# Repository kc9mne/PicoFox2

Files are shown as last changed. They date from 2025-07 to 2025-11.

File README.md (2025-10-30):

Below is the orginal info from AI6YM I have modified the code to enable multiple audio files named audio1.wav though audio8.wav played in order on a cycle.

# PicoFox – A Hackable 2m Fox Transmitter

**PicoFox** is an open source fox transmitter for the 2-meter amateur band, built around the
RP2040 microcontroller (the same chip used in the Raspberry Pi Pico). It’s designed to be simple,
functional, and easy to modify.

PicoFox works well as a standalone fox for portable or walking hunts, but it’s also a great platform
for experimentation. There's ample CPU, flash, and GPIO available if you want to add features like
sensors or interactivity. The transmitter can generate a frequency or phase modulated signal with up
to 2.5kHz (data) bandwidth.

## Key Features
- Transmits FM in the 144–148 MHz band (ITU Zone 1: 144–146 MHz).
- Configured by editing a text file — no software or terminal needed.
- Transmits any 5kHz 16-bit PCM WAV file.
- Automatic Morse code ID with configurable tone, speed, and spacing.
- RF output > 12dBm / 15mW.
- Charges over USB.
- Expansion header provides:
  - 12 GPIOs (including I2C, SPI, UART, ADC).
  - Regulated 3.3V and raw battery voltage.
  - Two additional SI5351 clock outputs

### Getting One

Fully assembled PicoFox units are available from [AI6YM.radio](https://ai6ym.radio/picofox). An
enclosure, battery, and antenna are included. I ship nearly anywhere in the world.

You can also build your own - both the hardware and software are open source for non-commercial use.
For commercial inquiries, contact [justin@ai6ym.radio](mailto:justin@ai6ym.radio).

## Configuration

To configure your PicoFox, connect it to any computer using a micro USB cable. It will appear as a
USB mass storage device (like a flash drive). Open `settings.txt` with a text editor and adjust the
configuration values as needed. Eject the drive, disconnect USB, and power cycle the PicoFox to
apply the new settings.

To reset to factory settings, delete `settings.txt`, eject the drive, disconnect USB, and power
cycle the PicoFox. A default settings file will be regenerated.

### Settings Overview

- `CALLSIGN`: Alphanumeric callsign (max 12 characters).
- `ITU_ZONE`: ITU zone where the transmitter operates (`1`, `2`, or `3`).
- `FREQ_MHZ`: Transmit frequency in MHz.
- `DUTY_CYCLE`: Transmit duty cycle percentage (`0–100`).
- `MORSE_WPM`: Morse ID speed in words per minute.
- `MORSE_FARNSWORTH_WPM`: Slower Farnsworth spacing speed (ignored if lower than `MORSE_WPM`).
- `MORSE_TONE`: Morse tone frequency (100–2000 Hz).
- `MORSE_TONE_VOL`: Morse tone volume percentage (`1–100`).

**Note:** Invalid or missing values may disable the transmitter or revert to safe defaults.

## Using the Transmitter

After configuring settings as described above. The transmitter will turn on following the
provided settings the next time it is turned on.

The transmitter may be powered by an external USB power supply or the internal battery. The internal
battery charges over USB but no indication is available to show battery charging.

**Note: The power switch must be ON to charge the battery over USB. The transmitter will run on USB
power with the switch OFF but the battery will NOT be charged.**

A full battery will last about five hours at 100% duty cycle, 

## Replacing the Audio File

To change the audio transmission, replace the `audio.wav` file in the device’s flash storage. The
audio must be sampled at **5kHz**, **mono** (one channel), and encoded as **signed 16-bit PCM WAV**.

Using **Audacity** (free software available for all major OSs):

1. Set "Project Rate (Hz)" to `5000`.
2. Import, record, or generate your audio.
3. Mix down to a single mono track.
4. Export as WAV using **Signed 16-bit PCM** encoding.
5. Name the file `audio.wav` and copy it to the device.
6. Eject the drive and disconnect USB.
7. Power cycle the PicoFox.

**Notes:**

- Improper format may prevent audio transmission or cause noise to be transmitted instead.
- The audio is transmitted, followed by the morse ID, and then the transmitter turns off if
  `DUTY_CYCLE < 100`. In this way the length of the audio determines the transmit cycle time and the
  frequency of morse code ID transmissions. **YOU ARE RESPONSIBLE FOR COMPLYING WITH LOCAL LAWS FOR
  TRANSMITTING YOUR CALLSIGN!**
- To restore the default audio, delete `audio.wav`, eject the drive, disconnect USB, and power cycle
  the PicoFox.

## Design Brief

An SI5351 clock generator, locked to a TCXO, provides the RF signal. Modulation is applied in
software by the RP2040. To achieve smooth FM output, modulation is handled on core 1 with
I<sup>2</sup>C running at 1 MHz. Register writes are minimized and no other devices are on
I<sup>2</sup>C0.

Core 0 manages flash operations. Most extensions or new features should run on core 0.

**Note:** Mounting the device as a USB mass storage device will interrupt clean modulation as both
cores are blocked during flash operations.

The SPI flash device is split into program memory and a FAT16 filesystem. The filesystem contains
a text file for user-supplied settings, an audio file for transmission, a second audio file
containing the generated morse code ID, and a hash file used to detect changes to the settings file.
Unexpected files are automatically deleted and missing files are re-created from defaults in the
firmware binary.

The design intentionally includes large amounts of free CPU cycles, RAM, and flash so that cool
things can be built on the PicoFox.

## Development Guide

### Build Environment Setup

- Install Arduino IDE >= 2.3.
- Install libraries - Adafruit SPIFlash, Adafruit TinyUSB, Etherkit Si5351.
- Install board package from [my fork of Arduino-Pico](https://github.com/ai6ym/arduino-pico). This
  will be merged upstream eventually but for now you'll need the changes in my fork.
- In `Tools -> Board` select the `Raspberry Pi RP2040/RP2350 Boards -> AI6YM PicoFox`.
- Connect your PicoFox and select the appropriate TTY / COM port.

On Linux it may be necessary to add udev rules for this device. The relevant rules from my system
are below. I have no idea how this works on other operating systems. Mac is probably similar,
Windows should not be used for software developement of any kind (or really anything).

```
# Make an RP2040 in BOOTSEL mode writable by all users, so you can `picotool`
# without `sudo`. 
SUBSYSTEM=="usb", ATTRS{idVendor}=="2e8a", ATTRS{idProduct}=="0003", MODE="0666"

# Symlink an RP2040 running MicroPython from /dev/pico.
#
# Then you can `mpr connect $(realpath /dev/pico)`.
SUBSYSTEM=="tty", ATTRS{idVendor}=="2e8a", ATTRS{idProduct}=="0005", SYMLINK+="pico"

# Adafruit TinyUSB stack.
SUBSYSTEM=="tty", ATTRS{idVendor}=="239a", ATTRS{idProduct}=="cafe", MODE="0666"
SUBSYSTEM=="usb", ATTRS{idVendor}=="239a", ATTRS{idProduct}=="cafe", MODE="0666"
```

### Compilation Settings

- `Flash Size`: `16MB (Sketch: 1MB, FS: 15MB)`
- `CPU Speed`: `TBD`
- `USB Stack`: `Adafruit TinyUSB`

If needed for some reason you could change the partition layout to give more space for the sketch.
Doing so would destroy all data but the code automatically formats the partition and writes
defaults.

All other settings are fine at default values.

### Recovering a Board

In general the UF2 upload process will work fine. Click the upload button, after compilation the IDE
will push the board into UF2 update mode, write the new binary, and then reset the board to normal
operation.

If that doesn't work try the following:
- Reset the board and try again. Just tap the `RESET` button on the board to reset the RP2040.
- Force the device into `BOOTSEL` mode. Hold the `BOOTSEL` button, tap the `RESET` button, and then
  release the `BOOTSEL` button.
- Force the device into `BOOTSEL` mode **AND** change `Tools -> Upload Method` to `PicoTool`.
- When all else fails grab a PicoProbe (or a Pico / Pico2 flashed with the PicoProbe binary),
  connect that to the debug header of the PicoFox, and change `Tools -> Upload Method` to
  `Picoprobe`.
- If all of the above fails, well, he's dead Jim.

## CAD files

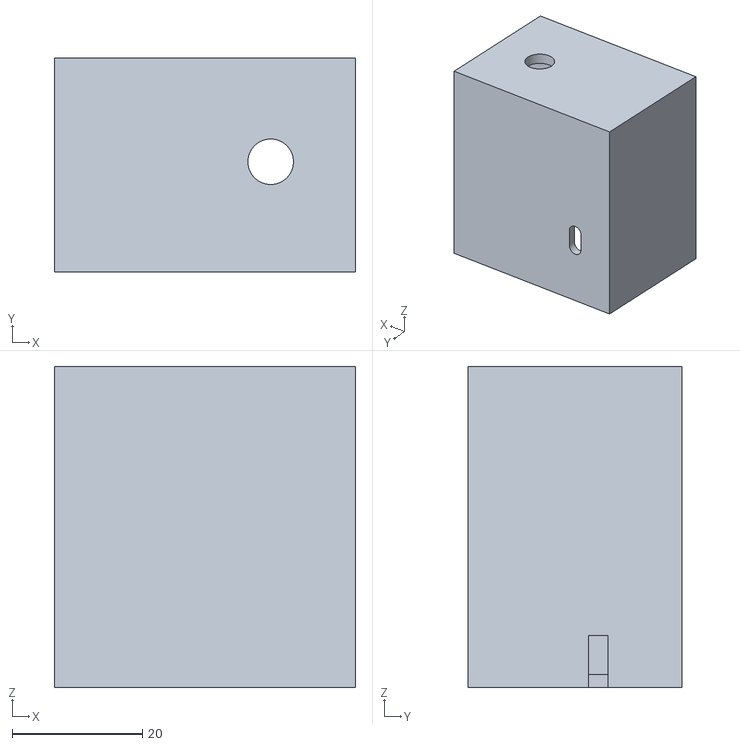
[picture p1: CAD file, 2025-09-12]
enclosure/Enclosure Body.stl
46.3 x 32.9 x 49.3

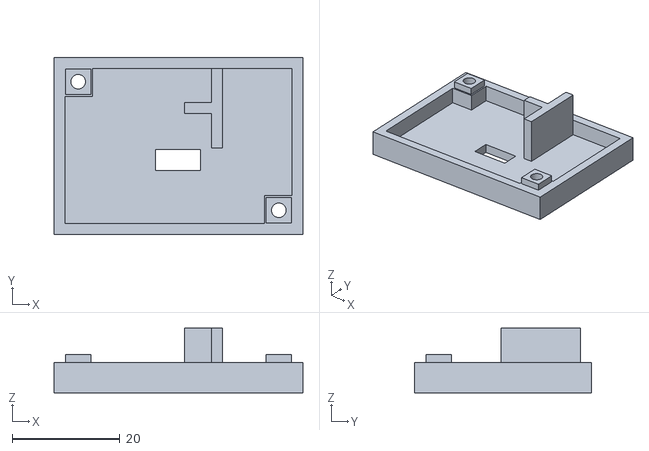
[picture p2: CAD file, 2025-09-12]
enclosure/Enclosure Top.stl
46.3 x 32.9 x 12.0

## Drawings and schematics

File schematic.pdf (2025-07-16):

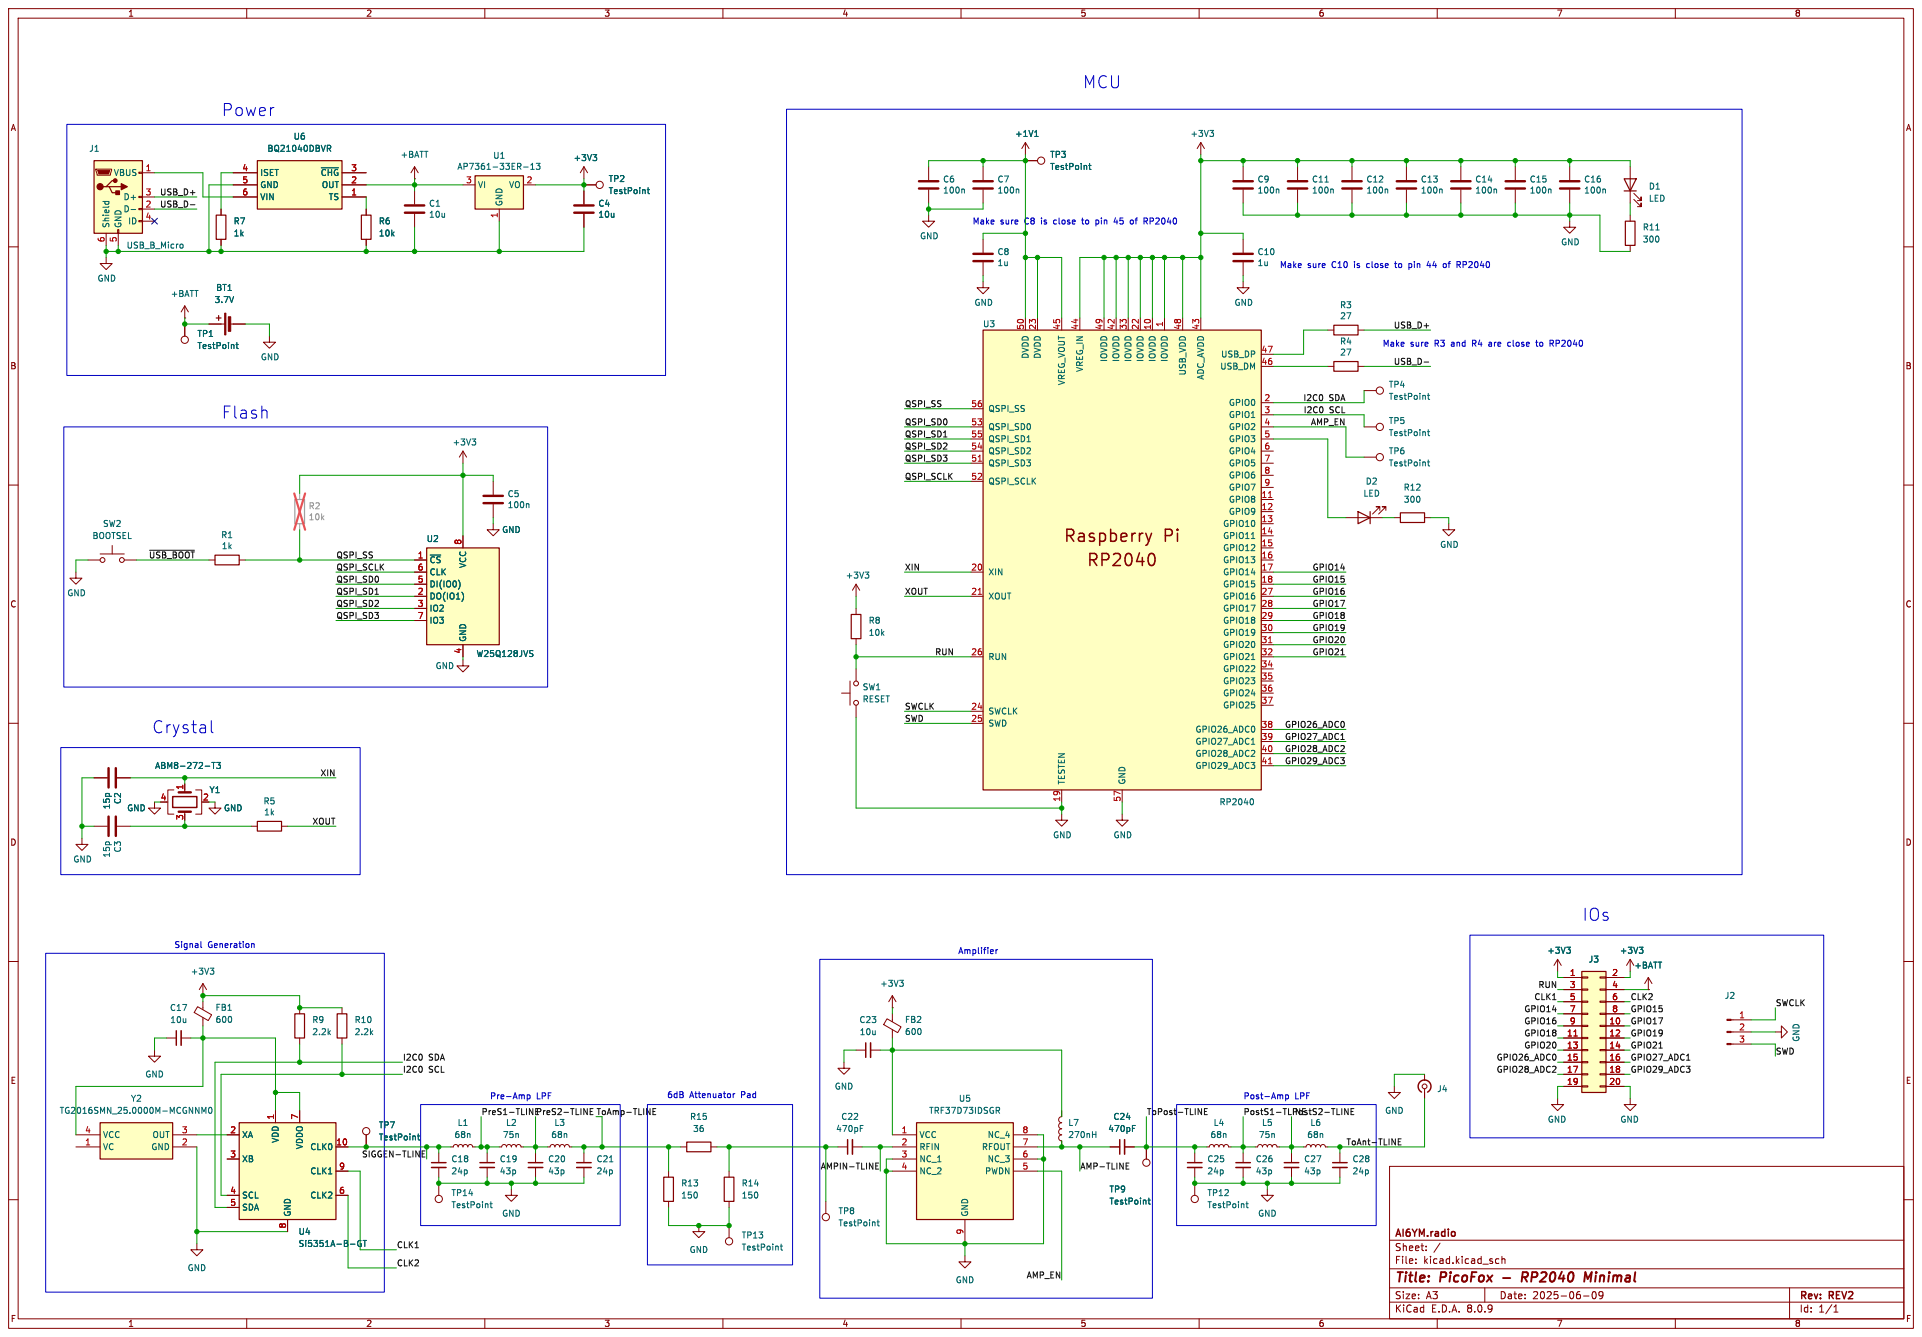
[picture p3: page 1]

1 IOVDD 10 GPIO8 11 GPIO9 12 GPIO10 13 GPIO11 14 GPIO12 15 GPIO13 16 GPIO14 17 GPIO15 18 TESTEN 19 GPIO0 2 XIN 20 XOUT 21 IOVDD 22 DVDD 23 SWCLK 24 SWD 25 RUN 26 GPIO16 27 GPIO17 28 GPIO18 29 GPIO1 3 GPIO19 30 GPIO20 31 GPIO21 32 IOVDD 33 GPIO22 34 GPIO23 35 GPIO24 36 GPIO25 37 GPIO26_ADC0 38 GPIO27_ADC1 39 GPIO2 4 GPIO28_ADC2 40 GPIO29_ADC3 41 IOVDD 42 ADC_AVDD 43 VREG_IN 44 VREG_VOUT 45 USB_DM 46 USB_DP 47 USB_VDD 48 IOVDD 49 GPIO3 5 DVDD 50 QSPI_SD3 51 QSPI_SCLK 52 QSPI_SD0 53 QSPI_SD2 54 QSPI_SD1 55 QSPI_SS 56 GND 57 GPIO4 6 GPIO5 7 GPIO6 8 GPIO7 9 U3 RP2040 GND

1 CLK0 10 XA 2 XB 3 SCL 4 SDA 5 CLK2 6 VDDO

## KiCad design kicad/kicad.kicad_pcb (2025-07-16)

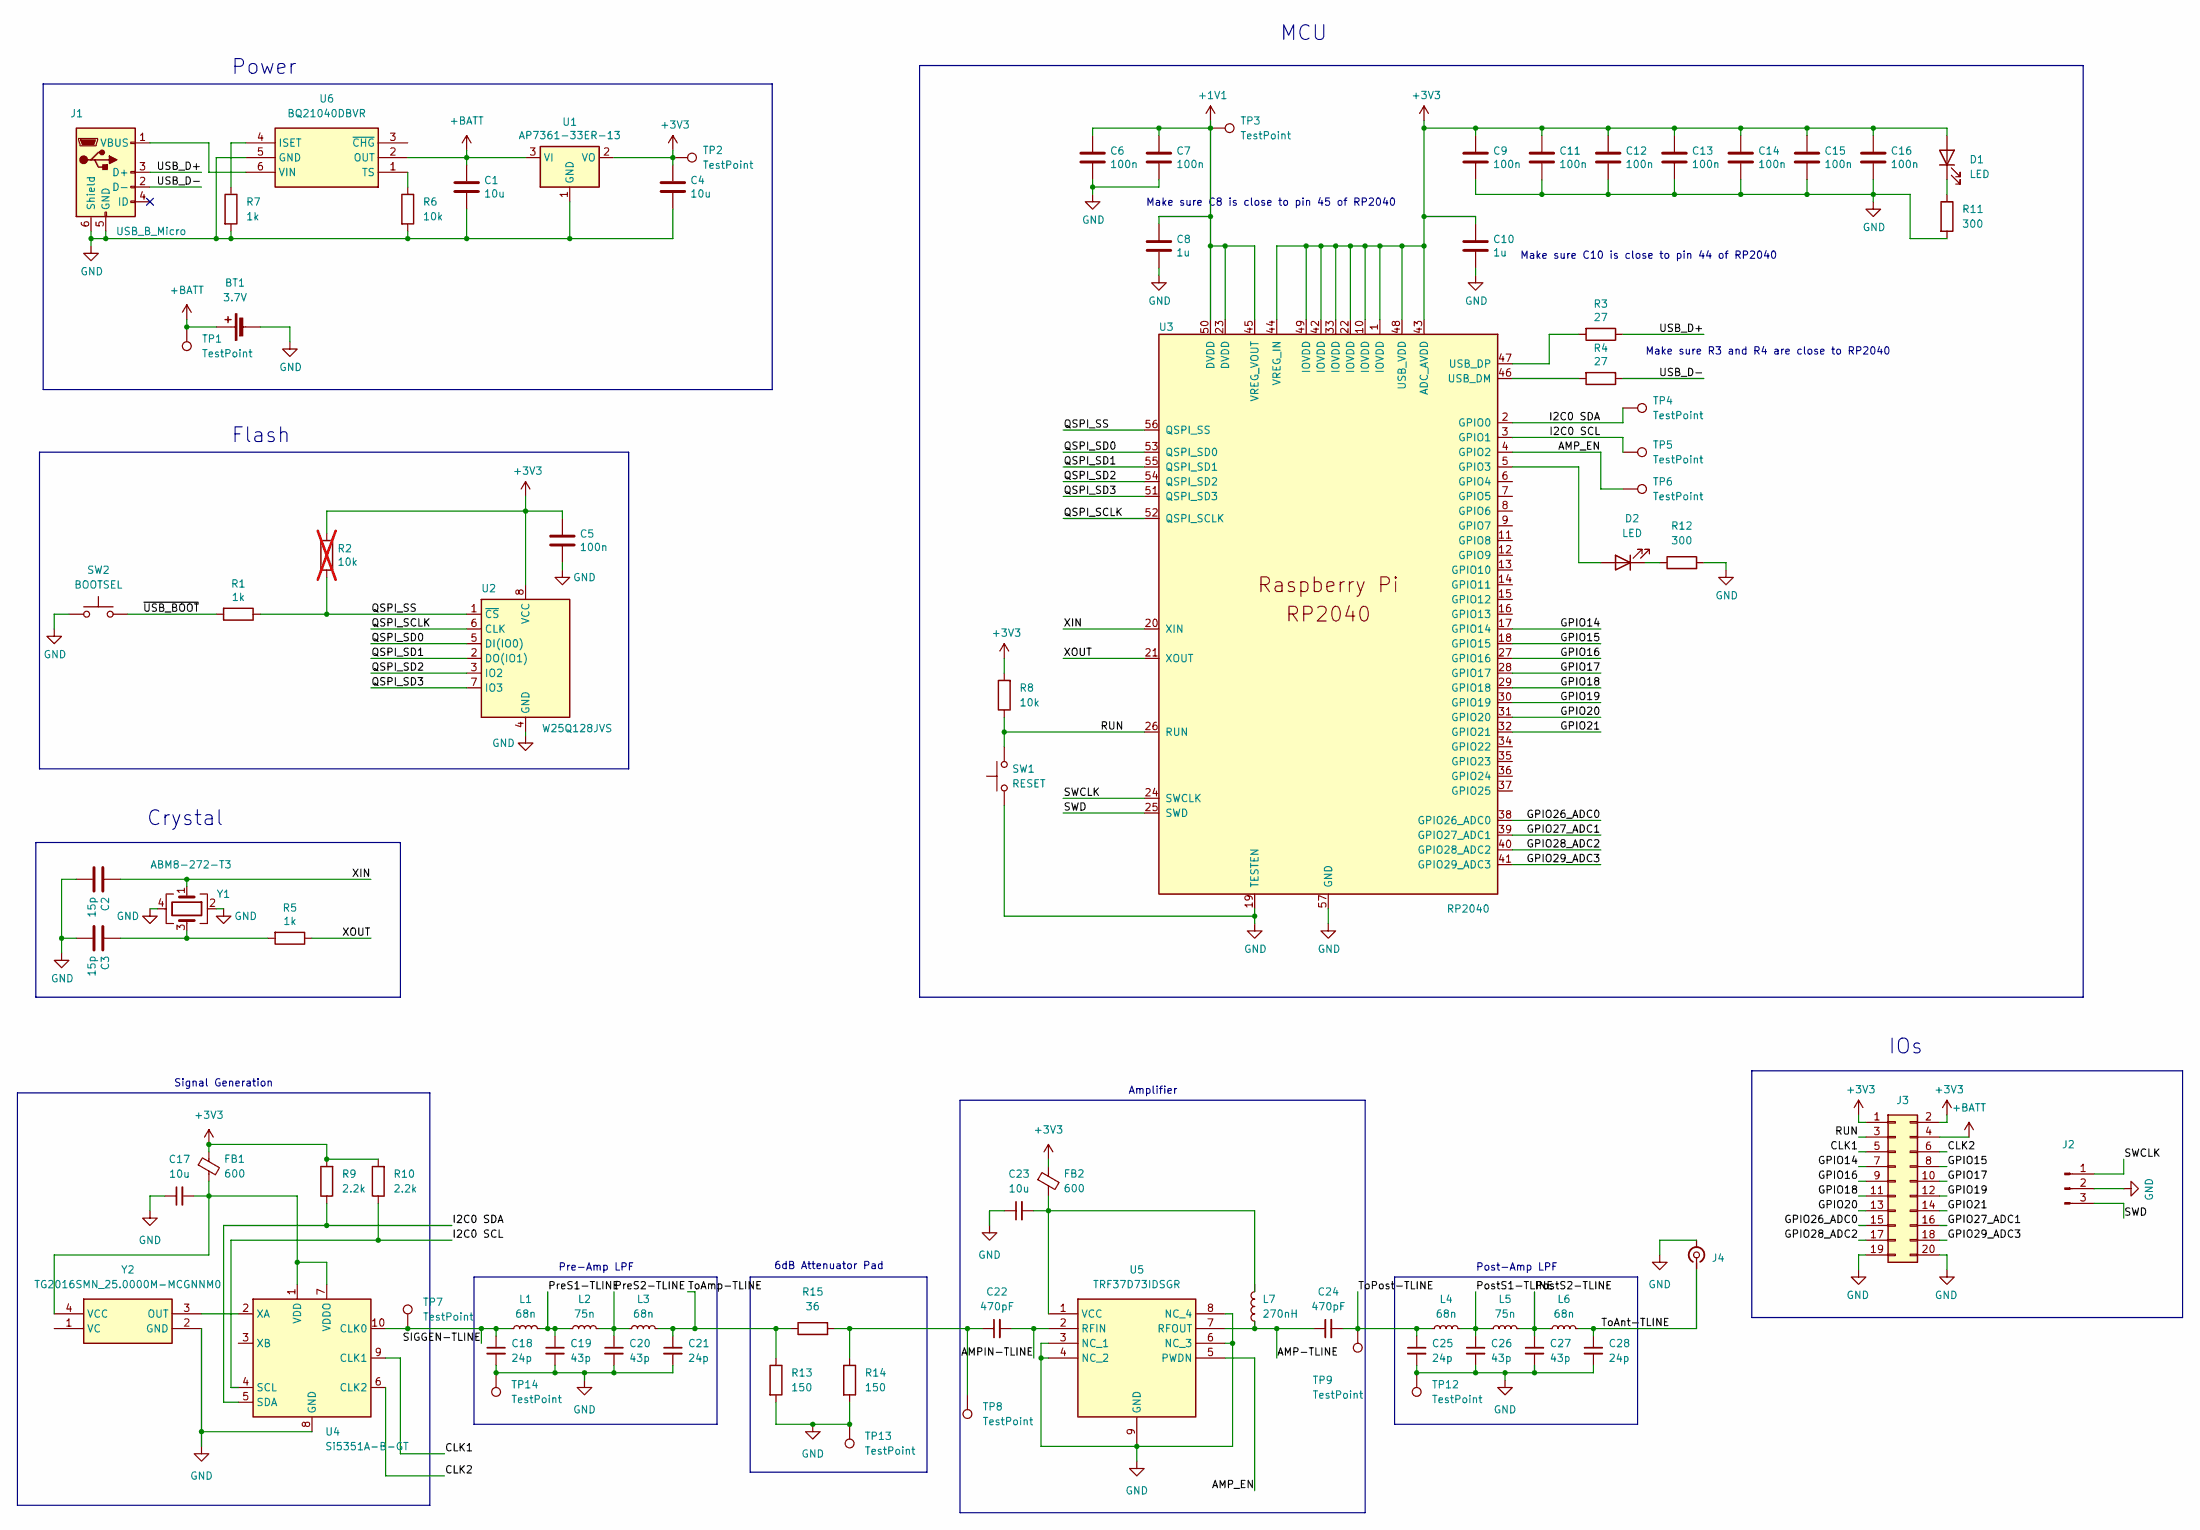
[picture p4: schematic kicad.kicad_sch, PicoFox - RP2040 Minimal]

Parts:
BT1: 3.7V; JST_PH_B2B-PH-K_1x02_P2.00mm_Vertical
C1, C4, C17, C23: 10u; C_0402_1005Metric
C2, C3: 15p; C_0402_1005Metric
C5, C6, C7, C9, C11, C12, C13, C14, C15, C16: 100n; C_0402_1005Metric
C8, C10: 1u; C_0402_1005Metric
C18, C21, C25, C28: 24p; C_0402_1005Metric
C19, C20, C26, C27: 43p; C_0402_1005Metric
C22, C24: 470pF; C_0402_1005Metric
D1, D2: LED; LED_0805_2012Metric
FB1, FB2: 600; L_0402_1005Metric
J1: USB_B_Micro; USB_Micro-B_Amphenol_10103594-0001LF_Horizontal_modified
J2: Conn_01x03_Pin; PinHeader_1x03_P2.54mm_Vertical
J3: Conn_02x10_Counter_Clockwise; PinHeader_2x10_P2.54mm_Vertical
J4: Conn_Coaxial_Small; SMA_Amphenol_901-143_Horizontal
L1, L3, L4, L6: 68n; L_0402_1005Metric
L2, L5: 75n; L_0402_1005Metric
L7: 270nH; L_0402_1005Metric
R1, R5, R7: 1k; R_0402_1005Metric
R2: 10k; R_0402_1005Metric; not fitted
R3, R4: 27; R_0402_1005Metric
R6, R8: 10k; R_0402_1005Metric
R9, R10: 2.2k; R_0402_1005Metric
R11, R12: 300; R_0402_1005Metric
R13, R14: 150; R_0402_1005Metric
R15: 36; R_0402_1005Metric
SW1: RESET; SW_Push_SPST_NO_Alps_SKRK
SW2: BOOTSEL; SW_Push_SPST_NO_Alps_SKRK
TP1, TP2, TP3, TP4, TP5, TP6, TP7, TP8, TP9, TP12, TP13, TP14: TestPoint; TestPoint_Pad_D1.0mm
U1: AP7361-33ER-13; SOT-223-3_TabPin2
U2: W25Q128JVS; SOIC-8_5.23x5.23mm_P1.27mm
U3: RP2040; RP2040-QFN-56
U4: Si5351A-B-GT; MSOP-10_3x3mm_P0.5mm
U5: TRF37D73IDSGR; WSON-8-1EP_2x2mm_P0.5mm_EP0.9x1.6mm; Mouser Part Number 595-TRF37D73IDSGR
U6: BQ21040DBVR; SOT95P280X145-6N; Mouser Part Number 595-BQ21040DBVR
Y1: ABM8-272-T3; Crystal_SMD_3225-4Pin_3.2x2.5mm
Y2: TG2016SMN_25.0000M-MCGNNM0; TG2016SMN250000MMCGNNM0; Mouser Part Number 732-2016SMN25MCGNNM0

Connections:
+1V1: C6.1, C7.1, C8.1, TP3.1, U3.23 (DVDD), U3.45 (VREG_VOUT), U3.50 (DVDD)
+3V3: C4.1, C5.1, C9.1, C10.1, C11.1, C12.1, C13.1, C14.1, C15.1, C16.1, D1.2 (A), FB1.1, FB2.1, J3.1, J3.2, R2.1, R8.2, R9.2, R10.2, TP2.1, U1.2 (VO), U2.8 (VCC), U3.1 (IOVDD), U3.10 (IOVDD), U3.22 (IOVDD), U3.33 (IOVDD), U3.42 (IOVDD), U3.43 (ADC_AVDD), U3.44 (VREG_IN), U3.48 (USB_VDD), U3.49 (IOVDD)
+BATT: BT1.1 (+), C1.1, J3.4, TP1.1, U1.3 (VI), U6.2 (OUT)
/AMP-TLINE: C24.1, L7.1, U5.7 (RFOUT); also elsewhere on the board
/AMPIN-TLINE: C22.2, U5.2 (RFIN)
/AMP_EN: TP6.1, U3.4 (GPIO2), U5.5 (PWDN)
/CLK1: J3.5, U4.9 (CLK1)
/CLK2: J3.6, U4.6 (CLK2)
/GPIO14: J3.7, U3.17 (GPIO14)
/GPIO15: J3.8, U3.18 (GPIO15)
/GPIO16: J3.9, U3.27 (GPIO16)
/GPIO17: J3.10, U3.28 (GPIO17)
/GPIO18: J3.11, U3.29 (GPIO18)
/GPIO19: J3.12, U3.30 (GPIO19)
/GPIO20: J3.13, U3.31 (GPIO20)
/GPIO21: J3.14, U3.32 (GPIO21)
/GPIO26_ADC0: J3.15, U3.38 (GPIO26_ADC0)
/GPIO27_ADC1: J3.16, U3.39 (GPIO27_ADC1)
/GPIO28_ADC2: J3.17, U3.40 (GPIO28_ADC2)
/GPIO29_ADC3: J3.18, U3.41 (GPIO29_ADC3)
/I2C0 SCL: R10.1, TP5.1, U3.3 (GPIO1), U4.4 (SCL)
/I2C0 SDA: R9.1, TP4.1, U3.2 (GPIO0), U4.5 (SDA)
/PostS1-TLINE: C26.1, L4.2, L5.1
/PostS2-TLINE: C27.1, L5.2, L6.1
/PreS1-TLINE: C19.1, L1.2, L2.1
/PreS2-TLINE: C20.1, L2.2, L3.1
/QSPI_SCLK: U2.6 (CLK), U3.52 (QSPI_SCLK)
/QSPI_SD0: U2.5 (DI(IO0)), U3.53 (QSPI_SD0)
/QSPI_SD1: U2.2 (DO(IO1)), U3.55 (QSPI_SD1)
/QSPI_SD2: U2.3 (IO2), U3.54 (QSPI_SD2)
/QSPI_SD3: U2.7 (IO3), U3.51 (QSPI_SD3)
/QSPI_SS: R1.1, R2.2, U2.1 (~CS), U3.56 (QSPI_SS)
/RUN: J3.3, R8.1, SW1.2, U3.26 (RUN)
/SIGGEN-TLINE: C18.1, L1.1, TP7.1, U4.10 (CLK0)
/SWCLK: J2.1, U3.24 (SWCLK)
/SWD: J2.3, U3.25 (SWD)
/ToAmp-TLINE: C21.1, L3.2, R13.1, R15.1
/ToAnt-TLINE: C28.1, J4.1 (In), L6.2
/ToPost-TLINE: C24.2, C25.1, L4.1, TP9.1
/USB_D+: J1.3 (D+), R3.1
/USB_D-: J1.2 (D-), R4.1
/XIN: C2.1, U3.20 (XIN), Y1.1
/XOUT: R5.1, U3.21 (XOUT)
/~USB_BOOT: R1.2, SW2.2
GND: BT1.2 (-), C1.2, C2.2, C3.2, C4.2, C5.2, C6.2, C7.2, C8.2, C9.2, C10.2, C11.2, C12.2, C13.2, C14.2, C15.2, C16.2, C17.1, C18.2, C19.2, C20.2, C21.2, C23.1, C25.2, C26.2, C27.2, C28.2, J1.5 (GND), J1.6 (Shield), J2.2, J3.19, J3.20, J4.2 (Ext), R6.2, R7.2, R11.2, R12.2, R13.2, R14.2, SW1.1, SW2.1, TP12.1, TP13.1, TP14.1, U1.1 (GND), U2.4 (GND), U3.19 (TESTEN), U3.57 (GND), U4.8 (GND), U5.3 (NC_1), U5.4 (NC_2), U5.6 (NC_3), U5.8 (NC_4), U5.9 (GND), U6.5 (GND), Y1.2, Y1.4, Y2.2 (GND)
unnamed: C3.1, R5.2, Y1.3
unnamed: C22.1, R14.1, R15.2, TP8.1
unnamed: D1.1 (K), R11.1
unnamed: D2.2 (A), U3.5 (GPIO3)
unnamed: D2.1 (K), R12.1
unnamed: J1.1 (VBUS), U6.6 (VIN)
unnamed: R4.2, U3.46 (USB_DM)
unnamed: R3.2, U3.47 (USB_DP)
unnamed: C17.2, FB1.2, U4.1 (VDD), U4.7 (VDDO), Y2.4 (VCC)
unnamed: U4.2 (XA), Y2.3 (OUT)
unnamed 55: C23.2, FB2.2, U5.1 (VCC); also elsewhere on the board
unnamed: R7.1, U6.4 (ISET)
unnamed: R6.1, U6.1 (TS)

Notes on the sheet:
IOs
Power
Amplifier
Make sure C8 is close to pin 45 of RP2040
Crystal
Pre-Amp LPF
Make sure C10 is close to pin 44 of RP2040
Post-Amp LPF
Signal Generation
Make sure R3 and R4 are close to RP2040
Flash
6dB Attenuator Pad
MCU

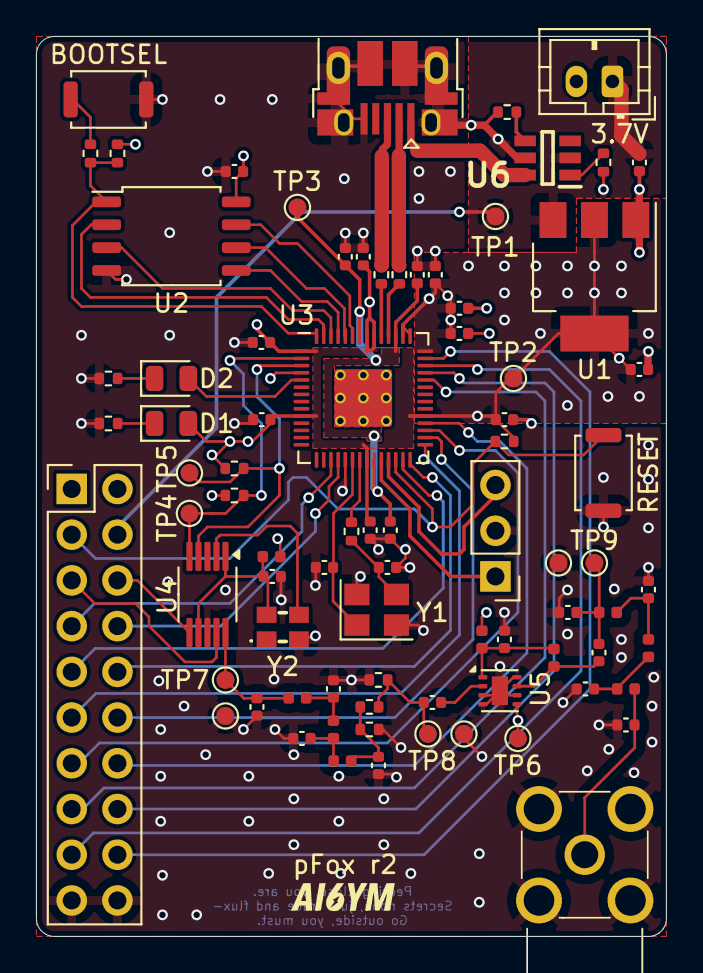
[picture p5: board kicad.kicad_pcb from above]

Board: 4 copper layers, 35.0 x 50.0 mm, 81 parts (0 on the bottom side), 58 nets.

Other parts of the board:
FB3: 600; L_0402_1005Metric

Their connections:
/AMP-TLINE: FB3.1; also elsewhere on the board
unnamed 55: FB3.2; also elsewhere on the board

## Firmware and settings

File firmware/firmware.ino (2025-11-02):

/* PicoFox - 2M FM Fox Transmitter

Modified BY KC9MNE to play multiple wav files in sequence, and have better audio quality.
below is AI6YM's original header, All base and foundational work is credited to him!
---------------------------------------------------------------------------------------
Copyright 2025 Giorgi Enterprises LLC dba AI6YM.radio.
License: Creative Commons Attribution-NonCommercial-ShareAlike 4.0 International (see LICENSE file).

COMMERCIAL USE OF THIS CODE AND ANY DERIVATIVE IS FORBIDDEN WITHOUT PERMISSION FROM THE COPYRIGHT HOLDER!

You may configure this software without compiling and flashing. Simply connect the device to your PC with a USB cable and edit the
settings.txt file. You may also change the audio which is played between morse code IDs by replacing the audio.wav file. The file you
provide MUST be 5kHz sampling, unsigned 16bit PCM audio.

The device may be reset to factory settings by deleting the settings.txt and audio.wav files. In factory settings the device WILL NOT
transmit. Configuring a callsign is required to enable the transmitter.
*/

#include <Arduino.h>
#include <Wire.h>
#include <si5351.h>
#include "SPI.h"
#include "SdFat_Adafruit_Fork.h"
#include "Adafruit_SPIFlash.h"
#include "Adafruit_TinyUSB.h"

#include "audio.h"

// #define DEBUG 1

#define AMP_EN 2u                            // Pin which enables the amplifier. Set LOW to enable, HIGH to disable.
#define AUDIO_SAMPLE_RATE_HZ 5000            // Audio sample rate (also rate of updates to SI5351).
#define FM_DEVIATION_HZ 10000                // Maximum RF deviation in Hz.
#define SI5351_PLL SI5351_PLLA               // PLL which will be used on the SI5351, consider this PLL unavailable for other purposes.
#define SI5351_CLOCK_OUTPUT SI5351_CLK0      // Clock output which drives RF circuitry.
#define SI5351_CLOCK_PARAM_START 42          // Register address on which multisynth parameters start.
#define SI5351_CLOCK_DIV 6                   // Fixed divider between PLL clock and MS.
#define SI5351_DRIVE_LEVEL SI5351_DRIVE_2MA  // Power output from SI5351, higher levels don't add much output but do create spurious emmissions.
#define SAMPLE_WRITE_CORR_US -3              // Time correction between sample writes to account for code which can't be measured.
#define MAX_UINT32 4294967295                // Maximum value for a 32 bit unsigned integer. Used to prevent glitches when micros() overflows.
#define NUM_AUDIO_FILES 11                    // Max number of audio file to create and use

// Frequency limitations.
#define MIN_FREQ_MHZ 144
#define MAX_FREQ_MHZ_ITU1 146  // ITU zone 1.
#define MAX_FREQ_MHZ 148       // ITU zones 2 and 3.

// RF Clock Gen
Si5351 si5351;

// Uses same external flash chip that the RP2040 is executing from. Size depends on Tools -> Flash Size setting.
Adafruit_FlashTransport_RP2040 flashTransport;
Adafruit_SPIFlash flash(&flashTransport);

// Filesystem and file descriptors.
FatFormatter formatter;
FatVolume fatfs;
FatFile root;
FatFile file;

// Controller for USB mass storage device.
Adafruit_USBD_MSC usb_msc;
bool hostMounted = false;

// Flash file names.
const char SETTINGS_TXT[] = "settings.txt";
const char AUDIO_WAV_1[] = "audio1.wav";
const char AUDIO_WAV_2[] = "audio2.wav";
const char AUDIO_WAV_3[] = "audio3.wav";
const char AUDIO_WAV_4[] = "audio4.wav";
const char AUDIO_WAV_5[] = "audio5.wav";
const char AUDIO_WAV_6[] = "audio6.wav";
const char AUDIO_WAV_7[] = "audio7.wav";
const char AUDIO_WAV_8[] = "audio8.wav";
const char AUDIO_WAV_9[] = "audio9.wav";
const char AUDIO_WAV_10[] = "audio10.wav";
const char AUDIO_WAV_11[] = "audio11.wav";
const char SETTINGS_CRC[] = ".settings_crc.bin";
const char CALLSIGN_WAV[] = "callsign.wav";

// Array of audio file names for easy cycling
const char* audioFiles[NUM_AUDIO_FILES] = {
  AUDIO_WAV_1, AUDIO_WAV_2, AUDIO_WAV_3, AUDIO_WAV_4,
  AUDIO_WAV_5, AUDIO_WAV_6, AUDIO_WAV_7, AUDIO_WAV_8,
  AUDIO_WAV_9, AUDIO_WAV_10, AUDIO_WAV_11
};

// Add variable to track current audio file (add near the Settings declaration, around line 100)
uint8_t currentAudioFile = 0;


// These files are allowed to be in flash, other files will be deleted.
const char* validFiles[] = {
  SETTINGS_TXT,
  AUDIO_WAV_1,
  AUDIO_WAV_2,
  AUDIO_WAV_3,
  AUDIO_WAV_4,
  AUDIO_WAV_5,
  AUDIO_WAV_6,
  AUDIO_WAV_7,
  AUDIO_WAV_8,
  AUDIO_WAV_9,
  AUDIO_WAV_10,
  AUDIO_WAV_11,
  CALLSIGN_WAV,
  SETTINGS_CRC,
};

const size_t numValidFiles = sizeof(validFiles) / sizeof(validFiles[0]);

// Default settings.
const char DEFAULT_CALLSIGN[12] = "";
const uint8_t DEFAULT_ITU_ZONE = 2;
const double DEFAULT_FREQ_MHZ = 146.565;
const uint8_t DEFAULT_DUTY_CYCLE = 100;
const uint8_t DEFAULT_WPM = 15;
const uint8_t DEFAULT_FARNSWORTH_WPM = 10;
const uint16_t DEFAULT_MORSE_TONE_HZ = 600;
const uint8_t DEFAULT_TONE_AMPLITUDE_PERCENT = 70;

// Config struct, start by loading defaults.
struct Settings {
  char callsign[12];
  uint8_t ituZone;
  double transmitFreqMHz;
  uint8_t dutyCyclePercent;
  uint8_t morseWPM;
  uint8_t farnsworthWPM;
  uint16_t morseToneHz;
  uint8_t toneAmplitudePercent;
  bool isConfigured;
};

Settings settings = {
  .callsign = { *DEFAULT_CALLSIGN },
  .ituZone = DEFAULT_ITU_ZONE,
  .transmitFreqMHz = DEFAULT_FREQ_MHZ,
  .dutyCyclePercent = DEFAULT_DUTY_CYCLE,
  .morseWPM = DEFAULT_WPM,
  .farnsworthWPM = DEFAULT_FARNSWORTH_WPM,
  .morseToneHz = DEFAULT_MORSE_TONE_HZ,
  .toneAmplitudePercent = DEFAULT_TONE_AMPLITUDE_PERCENT,
  .isConfigured = (strlen(DEFAULT_CALLSIGN) > 0)
};

int settingsCrc = 0;

// Creates a fat16 filesystem in the flash space.
void formatFat16(void) {
  uint8_t workbuf[4096];
  formatter.format(&flash, workbuf);
  if (fatfs.begin(&flash, true, 1, 0)) {
    Serial.println("Flash chip successfully formatted with new empty filesystem!");
  } else {
    Serial.println("Formatting failed. Good luck friend.");
    while (true)
      ;
  }
}

// Reads data from flash device.
int32_t mscReadCb(uint32_t lba, void* buffer, uint32_t bufsize) {
  return flash.readBlocks(lba, (uint8_t*)buffer, bufsize / 512) ? bufsize : -1;
}

// Writes data to the flash device.
int32_t mscWriteCb(uint32_t lba, uint8_t* buffer, uint32_t bufsize) {
  hostMounted = true;
  return flash.writeBlocks(lba, buffer, bufsize / 512) ? bufsize : -1;
}

// Flushes writes to flash.
void mscFlushCb(void) {
  flash.syncBlocks();
}

bool openRoot() {
  return root.openRoot(&fatfs);
}

void closeRoot() {
  root.close();
}

bool isFileInList(const char* name) {
  for (size_t i = 0; i < numValidFiles; i++) {
    if (strcmp(name, validFiles[i]) == 0) {
      return true;
    }
  }
  return false;
}

// Modified flashCleanup() function - replace the audio file check section
void flashCleanup() {
  // Open root filesystem.
  if (!openRoot()) {
    Serial.println("failed to open rootfs");
  }

  // List files and delete any that don't belong here.
  while (file.openNext(&root, O_RDWR)) {
    char name[64];
    file.getName(name, sizeof(name));
    if (!isFileInList(name)) {
      file.remove();
      Serial.print("Removing ");
      Serial.println(name);
    }
    file.close();
  }

  // Write the default settings if settings file is missing.
  if (!root.exists(SETTINGS_TXT)) {
    saveDefaultSettings();
    Serial.println("No settings file found. Writing default settings.");
  }

  // Write the default audio for any missing audio files.
  for (int i = 0; i < NUM_AUDIO_FILES; i++) {
    if (!root.exists(audioFiles[i])) {
      saveDefaultAudio(audioFiles[i]);
      Serial.print("No audio file found: ");
      Serial.print(audioFiles[i]);
      Serial.println(". Writing default audio.");
    }
  }

  // Close the filesytem.
  closeRoot();
}

// Saves the default settings struct to the settings.txt file in flash.
void saveDefaultSettings() {
  char buffer[512];
  snprintf(
    buffer,
    sizeof(buffer),
    "CALLSIGN=%s\nITU_ZONE=%u\nFREQ_MHZ=%.6f\nDUTY_CYCLE=%u\nMORSE_WPM=%u\nMORSE_FARNSWORTH_WPM=%u\nMORSE_TONE=%u\nMORSE_TONE_VOL=%u\n",
    DEFAULT_CALLSIGN,
    DEFAULT_ITU_ZONE,
    DEFAULT_FREQ_MHZ,
    DEFAULT_DUTY_CYCLE,
    DEFAULT_WPM,
    DEFAULT_FARNSWORTH_WPM,
    DEFAULT_MORSE_TONE_HZ,
    DEFAULT_TONE_AMPLITUDE_PERCENT);
  file.open(&root, SETTINGS_TXT, O_RDWR | O_CREAT);
  file.write(buffer, strlen(buffer));
  file.close();
}

// Saves the default audio wav to the audio.wav file in flash.
void saveDefaultAudio(const char* filename) {
  file.open(&root, filename, O_RDWR | O_CREAT);
  file.write(wavHeader, sizeof(wavHeader));  // Write wav header once.
  // Loop default audio to produce longer playback between IDs and transmitter cycling.
  for (int i = 0; i < DEFAULT_AUDIO_LOOPS; i++) {
    file.write(defaultAudio, sizeof(defaultAudio));
  }
  file.close();
}

// Loads the settings.txt file in flash into a settings struct.
void loadSettings() {
  openRoot();
  if (!file.open(&root, SETTINGS_TXT, O_RDONLY)) {
    Serial.println("Failed to open settings.txt");
    return;
  }

  String line = "";
  int c;
  settingsCrc = 0;
  while ((c = file.read()) >= 0) {
    settingsCrc += c;
    char ch = (char)c;
    ch = toupper(ch);
    if (ch == '\n') {
      int sep = line.indexOf('=');
      if (sep == -1) continue;
      String key = line.substring(0, sep);
      String val = line.substring(sep + 1);
      if (key == "CALLSIGN") strncpy(settings.callsign, val.c_str(), sizeof(settings.callsign) - 1);
      else if (key == "ITU_ZONE") settings.ituZone = val.toInt();
      else if (key == "FREQ_MHZ") settings.transmitFreqMHz = val.toDouble();
      else if (key == "DUTY_CYCLE") settings.dutyCyclePercent = val.toInt();
      else if (key == "MORSE_WPM") settings.morseWPM = val.toInt();
      else if (key == "MORSE_FARNSWORTH_WPM") settings.farnsworthWPM = val.toInt();
      else if (key == "MORSE_TONE") settings.morseToneHz = val.toInt();
      else if (key == "MORSE_TONE_VOL") settings.toneAmplitudePercent = val.toInt();
      line = "";
    } else {
      line += ch;
    }
  }
  file.close();
  closeRoot();

  // Validate config and apply defaults when config is weird.
  if (settings.dutyCyclePercent > 100) {
    settings.dutyCyclePercent = DEFAULT_DUTY_CYCLE;
  }
  if (settings.morseWPM == 0 || settings.morseWPM > 30) {
    settings.morseWPM = DEFAULT_WPM;
  }
  if (settings.farnsworthWPM == 0 || settings.farnsworthWPM < settings.morseWPM) {
    settings.farnsworthWPM = settings.morseWPM;
  }
  if (settings.morseToneHz < 100 || settings.morseToneHz >= 2500) {
    settings.morseToneHz = DEFAULT_MORSE_TONE_HZ;
  }
  if (settings.toneAmplitudePercent == 0 || settings.toneAmplitudePercent > 100) {
    settings.toneAmplitudePercent = DEFAULT_TONE_AMPLITUDE_PERCENT;
  }

  // Disable transmitter if no callsign is set.
  settings.isConfigured = (strlen(settings.callsign) > 0);

  // Disable transmitter if transmit frequency is out of band.
  uint32_t transmitFreqHz = settings.transmitFreqMHz * 1e6;
  uint16_t deviationMarginHz = FM_DEVIATION_HZ * 2;
  uint32_t minFreqHz = MIN_FREQ_MHZ * 1e6 + deviationMarginHz;
  uint32_t maxFreqHz;
  if (settings.ituZone == 1) {
    maxFreqHz = MAX_FREQ_MHZ_ITU1 * 1e6 - deviationMarginHz;
  } else {
    maxFreqHz = MAX_FREQ_MHZ * 1e6 - deviationMarginHz;
  }
  if (transmitFreqHz < minFreqHz || transmitFreqHz > maxFreqHz) {
    settings.isConfigured = false;
  }
}

bool settingsChanged() {
  bool changed = false;

  // If the marker file can be opened for reading check for a match, assume regen needed if file open fails.
  if (file.open(&root, SETTINGS_CRC, O_RDONLY)) {
    int savedCrc;
    file.read((void*)&savedCrc, sizeof(savedCrc));
    file.close();
    if (savedCrc == settingsCrc) {
      return false;
    }
  }

  file.close();
  return true;
}

// Generates an audio morse code ID from the provided callsign.
void generateMorseAudio() {
  openRoot();
  if (!file.open(&root, CALLSIGN_WAV, O_RDWR | O_CREAT)) {
    Serial.println("Failed to open callsign.wav");
    return;
  }

  // Write wav header.
  file.write(wavHeader, sizeof(wavHeader));

  const int sampleRate = AUDIO_SAMPLE_RATE_HZ;
  const int toneFreq = settings.morseToneHz;
  const double ditLengthSec = 1.2f / settings.morseWPM;
  const double interCharLengthSec = 1.2f / settings.farnsworthWPM * 3;
  const double riseFall = (1.0f / 3.0f) * ditLengthSec * sampleRate;

  const int amplitude = (settings.toneAmplitudePercent * 32767) / 100;
  const double toneStep = 2.0f * PI * toneFreq / sampleRate;

  auto writeTone = [&](double durationSec) {
    int samples = (int)(durationSec * sampleRate);
    for (int i = 0; i < samples; i++) {
      double envelope = 1.0f;
      if (i < riseFall) envelope = i / riseFall;
      else if (i > samples - riseFall) envelope = (samples - i) / riseFall;
      int16_t sample = (int16_t)(amplitude * envelope * sinf(toneStep * i));
      file.write((uint8_t*)&sample, 2);
    }
  };

  auto writeSilence = [&](double durationSec) {
    int samples = (int)(durationSec * sampleRate);
    int16_t zero = 0;
    for (int i = 0; i < samples; i++) {
      file.write((uint8_t*)&zero, 2);
    }
  };

  const char* morseTable[36] = {
    ".-", "-...", "-.-.", "-..", ".", "..-.", "--.", "....", "..",
    ".---", "-.-", ".-..", "--", "-.", "---", ".--.", "--.-", ".-.",
    "...", "-", "..-", "...-", ".--", "-..-", "-.--", "--..",
    "-----", ".----", "..---", "...--", "....-",
    ".....", "-....", "--...", "---..", "----."
  };

  auto getMorse = [&](char c) -> const char* {
    if (c >= 'A' && c <= 'Z') return morseTable[c - 'A'];
    if (c >= '0' && c <= '9') return morseTable[c - '0' + 26];
    return "";
  };

  writeSilence(interCharLengthSec);
  for (int i = 0; settings.callsign[i] && i < 12; i++) {
    const char* symbol = getMorse(settings.callsign[i]);
    for (int j = 0; symbol[j]; j++) {
      if (j != 0) writeSilence(ditLengthSec);
      if (symbol[j] == '.') writeTone(ditLengthSec);
      else if (symbol[j] == '-') writeTone(3 * ditLengthSec);
    }
    writeSilence(interCharLengthSec);
  }
  file.close();

  // Write a marker to indicate that the current callsign was generated.
  file.open(&root, SETTINGS_CRC, O_RDWR | O_CREAT);
  file.write((const void*)&settingsCrc, sizeof(settingsCrc));
  file.close();

  closeRoot();
}

// Regenerates morse code ID audio if the callsign has changed.
void generateMorseIfNeeded() {
  openRoot();
  bool regenerate = true;

  // Check for changes in settings file.
  if (!settingsChanged()) {
    regenerate = false;
  }

  // Force regen if the callsign audio file is missing.
  if (!root.exists(CALLSIGN_WAV)) {
    regenerate = true;
  }
  closeRoot();

  if (regenerate) {
    Serial.println("Detected settings change, generating new callsign audio");
    generateMorseAudio();
  }
}

// Remove junk, load settings and audio data. Generate morse ID audio if necessary.
void loadFlashData() {
  flashCleanup();
  loadSettings();
  generateMorseIfNeeded();
}

// Enables and disables the si5351 clock output and the RF amplifier.
void setSi5351Output(bool enabled) {
  if (enabled && settings.dutyCyclePercent > 0) {
    si5351.output_enable(SI5351_CLOCK_OUTPUT, 1);
    digitalWrite(AMP_EN, LOW);
    digitalWrite(LED_BUILTIN, HIGH);
  } else {
    si5351.output_enable(SI5351_CLOCK_OUTPUT, 0);
    digitalWrite(AMP_EN, HIGH);
    digitalWrite(LED_BUILTIN, LOW);
  }
}

// Sets the output frequency of the si5351 based on a given deviation from the center frequency.
void setFrequencyOffset(double deviation) {
  uint64_t freq = (uint64_t)(((settings.transmitFreqMHz * 1e6) + deviation) * 100);
  uint64_t pll_freq = freq * SI5351_CLOCK_DIV;
  si5351.set_pll(pll_freq, SI5351_PLL);
}

// Sleeps until it is time to write the next sample, based on the start of the cycle writing the current sample.
void delayForNextSample(uint32_t start) {
  uint32_t sampleDelta = 1000000UL / AUDIO_SAMPLE_RATE_HZ + SAMPLE_WRITE_CORR_US;

  // At the boundary of micros() overflow. Sleep until the appropriate time AFTER the overflow.
  // Otherwise just sleep for the appropriate delta.
  if ((MAX_UINT32 - start) < sampleDelta) {
    while (micros() > start || micros() < (sampleDelta - (MAX_UINT32 - start)))
      ;
  } else {
    while (micros() - start < sampleDelta)
      ;
  }
}

// Generates narrowband frequency modulated RF from a given audio file.
uint32_t playAudio(const char* filename) {
  if (hostMounted) return 0;  // Refuse to play audio if the host is trying to use the filesystem.
  openRoot();
  if (!file.open(&root, filename, O_RDWR | O_CREAT)) {
    Serial.println("Failed to open audio file.");
    return 0;
  }

  // Load WAV header and validate
  uint32_t dataStart = 44;
  char header[44];
  if (file.read(header, 44) != 44) return 0;
  if (strncmp(header, "RIFF", 4) != 0 || strncmp(header + 8, "WAVE", 4) != 0) return 0;

  #ifdef DEBUG
  uint32_t startMicros = micros();
  #endif

  uint32_t numSamples = 0;
  int16_t sample;
  while (file.read((uint8_t*)&sample, 2) == 2) {
    // End playback early if host is trying to use the filesystem.
    if (hostMounted) {
      return 0;
    }
    uint32_t start = micros();

    // Frequency deviation mapping
    double deviation = ((double)sample * FM_DEVIATION_HZ) / 32767;
    setFrequencyOffset(deviation);

    // Wait until next sample time
    numSamples++;
    delayForNextSample(start);
  }

  #ifdef DEBUG
  uint32_t endMicros = micros();
  Serial.print("Total time (us) ");
  Serial.print(endMicros - startMicros);
  Serial.print(" total samples ");
  Serial.print(numSamples);
  Serial.print(" us per sample ");
  Serial.println((double)(endMicros - startMicros) / numSamples);
  #endif

  file.close();
  closeRoot();
  uint32_t audioLengthMs = numSamples * 1000 / AUDIO_SAMPLE_RATE_HZ;
  return audioLengthMs;
}

// Plays the given audio file and generated morse code id repeatedly.
void audioTask() {
  while (true) {
    if (hostMounted) {  // Cancel task if the host is trying to use the filesystem.
      setSi5351Output(false);
      break;
    }

    if (settings.isConfigured && settings.dutyCyclePercent > 0) {
      setSi5351Output(true);
      
      // Play the current audio file in the cycle
      uint32_t audioLengthMs = playAudio(audioFiles[currentAudioFile]);
      
      // Play the callsign after the audio
      audioLengthMs += playAudio(CALLSIGN_WAV);
      
      // Move to next audio file for next cycle
      currentAudioFile = (currentAudioFile + 1) % NUM_AUDIO_FILES;
      
      if (settings.dutyCyclePercent < 100) {
        uint32_t offTime = ((100 - settings.dutyCyclePercent) * audioLengthMs) / 100;
        setSi5351Output(false);
        delay(offTime);
      }
    } else {
      delay(1000);
    }
  }
}

void setup() {
  Serial.begin(115200);
  Serial.println("Serial Started...");

#ifdef DEBUG
  while (!Serial) delay(10);
#endif

  // Initialize flash device.
  while (!flash.begin()) {
    Serial.println("Flash setup failed.");
    delay(1000);
  }

  // Init file system on the flash
  if (!fatfs.begin(&flash, true, 1, 0)) {
    Serial.println("Flash not formatted, attempting to format.");
    formatFat16();
  }
  loadFlashData();

  // Init USB mass storage device.
  usb_msc.setID("AI6YM", "PicoFox", "2.0");
  usb_msc.setReadWriteCallback(mscReadCb, mscWriteCb, mscFlushCb);
  usb_msc.setCapacity(flash.size() / 512, 512);
  usb_msc.setUnitReady(true);
  usb_msc.begin();

  // Forces reenumeration when the device is reset.
  if (TinyUSBDevice.mounted()) {
    TinyUSBDevice.detach();
    delay(10);
    TinyUSBDevice.attach();
  }

  // Initialize pins for LED and Amp control.
  pinMode(AMP_EN, OUTPUT);
  digitalWrite(AMP_EN, HIGH);
  pinMode(LED_BUILTIN, OUTPUT);
  digitalWrite(LED_BUILTIN, LOW);

  // Initialize the si5351.
  Wire.setClock(1000000);  // >= 800kHz needed for sufficiently fast I2C writes.
  si5351.init(SI5351_CRYSTAL_LOAD_10PF, 0, 0);  // Set load expected by external TCXO.
  si5351.drive_strength(SI5351_CLOCK_OUTPUT, SI5351_DRIVE_LEVEL);  // Set drive strength.
  si5351.set_int(SI5351_CLOCK_OUTPUT, 1);  // Clock will be set to a fixed int mult, fine adjustment done on the PLL mult.
  si5351.set_pll((settings.transmitFreqMHz * 1e8) * SI5351_CLOCK_DIV, SI5351_PLL);  // Set the PLL frequency based on the target frequency.
  si5351.set_freq_manual(settings.transmitFreqMHz * 1e8, si5351.plla_freq, SI5351_CLOCK_OUTPUT);  // Let the library calculate and set the simple div by 6 MS.
  si5351.pll_reset(SI5351_PLL);  // Soft reset to get the PLL moving.
  Serial.println("si5351 setup complete.");

  // Start the audio playback task on the second core to prevent timing issues.
  multicore_launch_core1(audioTask);
}

void loop() {
}

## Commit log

2025-07-16 Initial commit, PicoFox r2.
    [kicad.kicad_pcb, kicad.kicad_sch]
2025-09-12 Added enclosure STLs.
    [Enclosure Body.stl, Enclosure Top.stl]
